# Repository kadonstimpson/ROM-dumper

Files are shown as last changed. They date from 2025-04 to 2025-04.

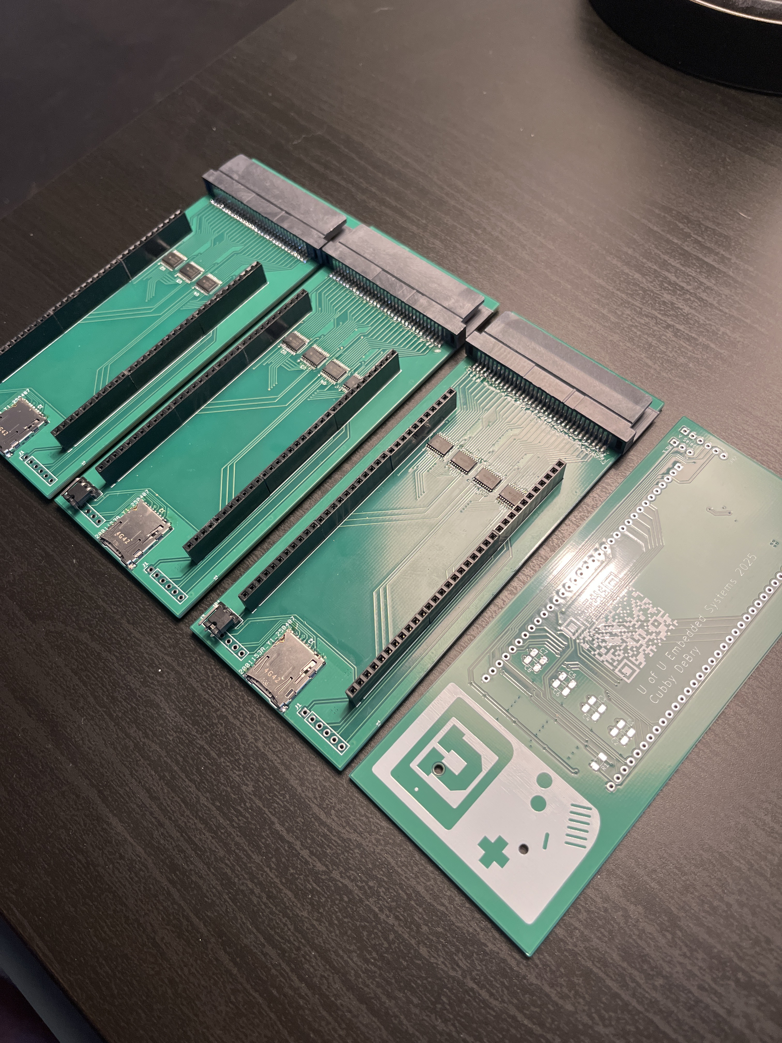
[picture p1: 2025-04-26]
Demo Material/Board_Fab.JPG

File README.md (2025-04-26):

# ROM‑Dumper for STM32F072 Discovery  
University of Utah • Embedded Systems Project

## Team Members
Cubby DeBry,  
Joshua Elieson,  
Kadon Stimpson,  
Yunzu Hou  

---

## Table of Contents
1. [About the Project](#about-the-project)  
2. [Hardware](#hardware)  
   * [Discovery‑board Modifications](#discovery-board-modifications)  
3. [Software](#software)  
   * [Supported Cartridge Types](#supported-cartridge-types)  
   * [Dumping Options](#dumping-options)  
4. [Getting Started](#getting-started)  
5. [Usage](#usage)  
6. [Roadmap / To‑Do](#roadmap--to-do)  

---

## About the Project
This project implements a **stand‑alone cartridge dumper** that interfaces classic Nintendo hand‑held game cards with an STM32F072 Discovery board.  
* **Hardware**—custom daughter‑board hosting the game‑card connector, level‑shifters and SD‑card slot.  
* **Firmware**—bank‑aware bus driver plus USB‑CDC and FatFS back‑ends.  
* **Host Tools**—minimal Python/Tk GUI for one‑click dumps on macOS, Windows, and Linux.

All design files live under `Hardware/`; Desktop tools reside in `Tools/`.

---

## Hardware
Design iteration **v1** is complete and electrically validated.  SD‑card and game‑card buses have been verified on real cartridges.

### Discovery‑board Modifications
The stock STM32F072 Discovery must be tweaked to expose additional GPIO lines:
| Component | Action |
|---|---|
| C26, C27, C28 | **Remove** |
| R38, R39, R40 | **Remove** |
| SBx (solder bridges on rear) | **Bridge** matching removed caps/resistors |

> **Orientation tip**: the Discovery board plugs into the daughter‑board with its **USB‑Mini port facing the SD‑card slot**. No directional silk is present, so double‑check before powering.

---

## Software
### Supported Cartridge Types
| System | Status | Notes |
|---|---|---|
| **Game Boy / Game Boy Color** |  | |
| &nbsp;&nbsp;No MBC | ✔ Implemented *(untested)*  | |
| &nbsp;&nbsp;MBC1 | ✔ Implemented *(untested)* | |
| &nbsp;&nbsp;MBC2 | ✔ Implemented *(untested)* | |
| &nbsp;&nbsp;MBC3 | ✔ Implemented *(untested)* | Pokemon, etc. |
| &nbsp;&nbsp;MBC5 | ✔ Implemented & **tested** | Almost all later games |
| &nbsp;&nbsp;MBC6 | ✔ Implemented *(untested)* | |
| &nbsp;&nbsp;MBC7 | ✔ Implemented *(untested)* | |
| &nbsp;&nbsp;Other/rare MBCs | ✖ Not yet | Handful of known games |
| **Game Boy Advance** | ✔ Full dumps (32 MiB assumed) | |

### Dumping Options
* **USB‑CDC** – streams data over 1 Mbaud VCP; proven with GBA cartridges.  
* **SD‑Card** – direct‐to‑FAT file dumps; already linked into MBC5 flow, pending integration for other types.

---

## Getting Started
```bash
# clone repository
git clone https://github.com/your‑org/ROM‑dumper.git
cd ROM‑dumper

# create virtual environment for host tools
python3 -m venv .venv
source .venv/bin/activate

# build firmware (requires arm‑gcc & stm32cubemx)
pio run -t upload
```

---

## Usage
### Stand‑alone (SD‑Card)
1. Insert a FAT formatted SD card.  
2. Power the board via USB. 
3. Insert cartridge
6. Press *Reset* button 
7. Retrieve `.gba`/`.gbc`/`.gb` file from SD.

### USB‑CDC
1. Power the board via USB. 
2. Run `dumperGUI.py`.
3. Select corresponding serial port from list.
4. Provide file name for dump output (including `.gba`/`.gbc`/`.gb`).
5. Press *Start Dump* button 
6. Retrieve `.gba`/`.gbc`/`.gb` file

---

## Roadmap / To‑Do
* **Mode selector**—hardware or menu to choose SD vs USB without a PC.  
* **DMA + double buffering** for both back‑ends to maximise throughput.  
* **GBA ROM trimming**—detect true ROM size to avoid 32 MiB paddings.  
* **Integrate SD flow** into all MBC drivers.
* **V2 Hardware** standalone dumper with lcd and onboard STM32.  
* **Automated self‑test** jig for production.

---

© 2025 University of Utah Embedded Systems Group • Licensed under MIT (see `LICENSE`).

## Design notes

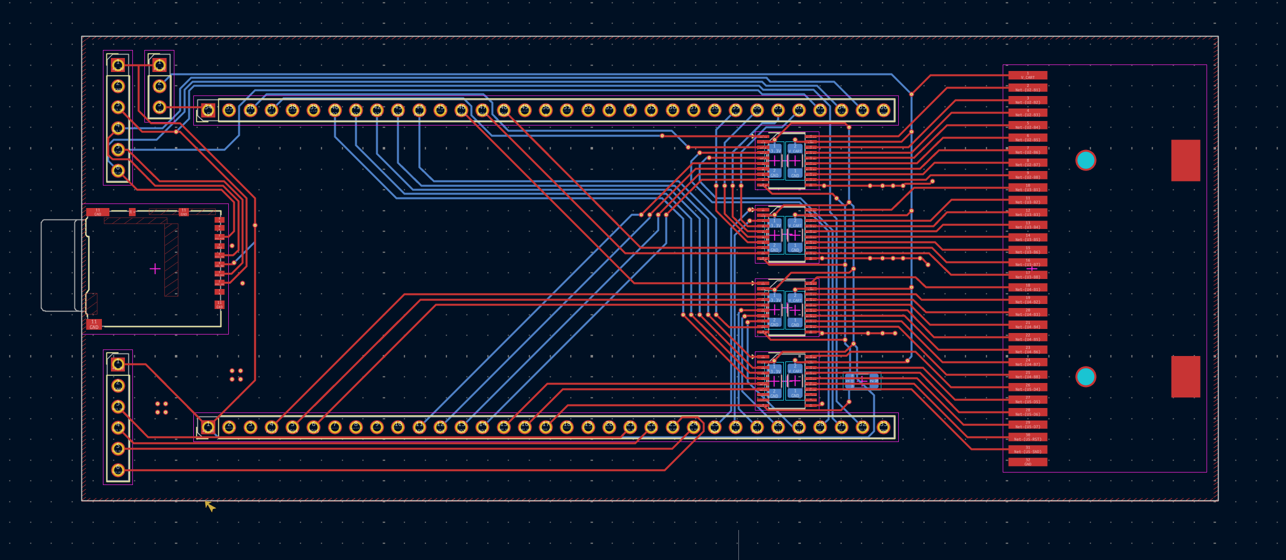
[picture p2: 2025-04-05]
Hardware/Screenshot 2025-04-05 at 1.11.22 AM.png

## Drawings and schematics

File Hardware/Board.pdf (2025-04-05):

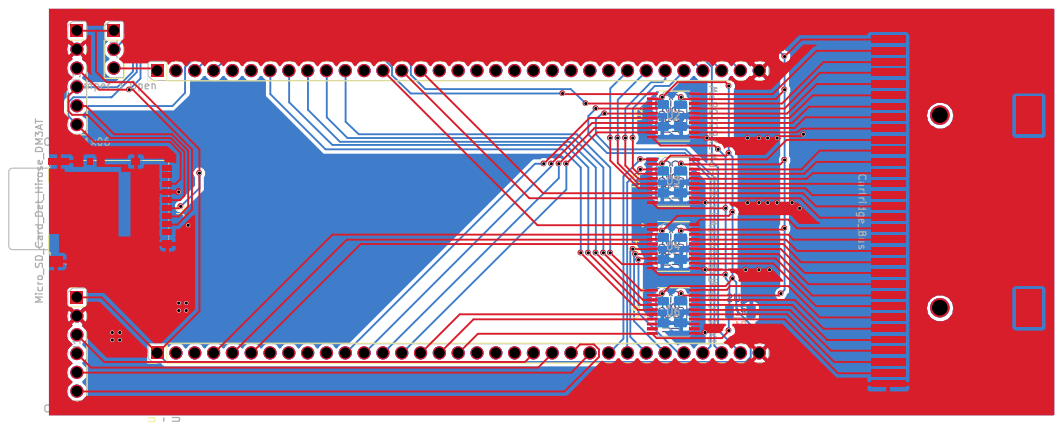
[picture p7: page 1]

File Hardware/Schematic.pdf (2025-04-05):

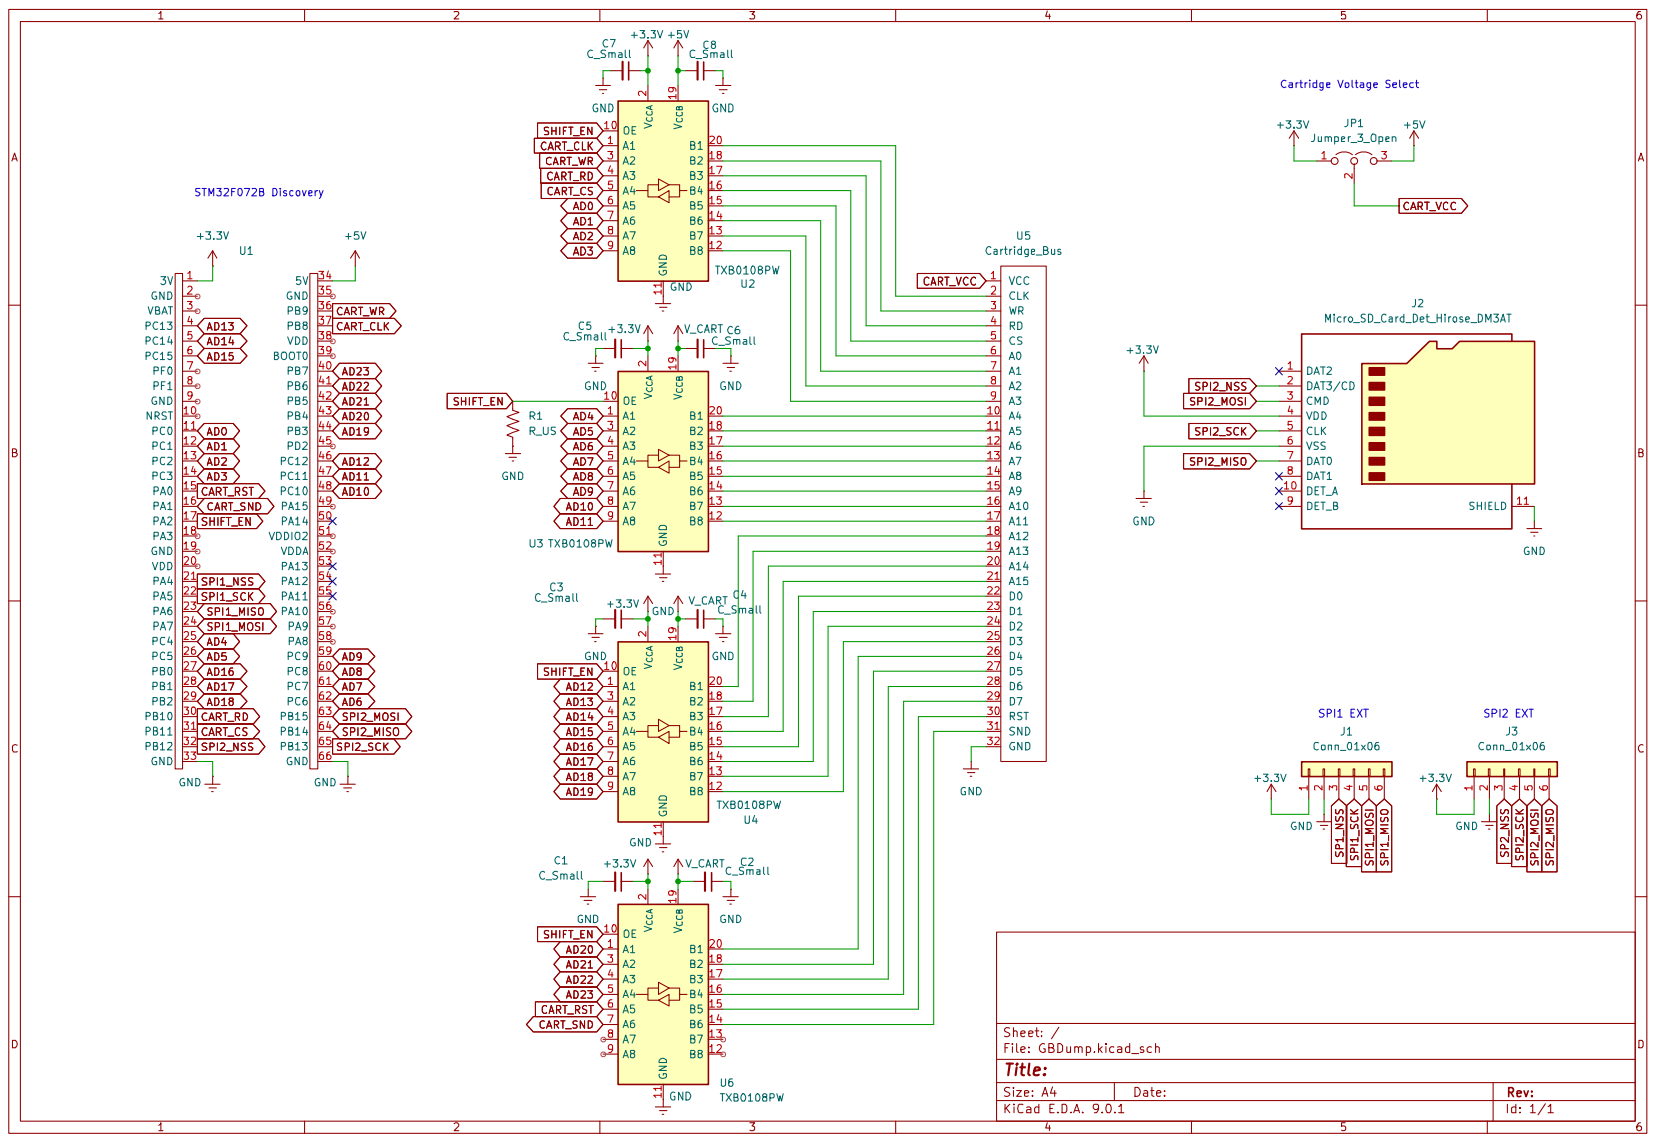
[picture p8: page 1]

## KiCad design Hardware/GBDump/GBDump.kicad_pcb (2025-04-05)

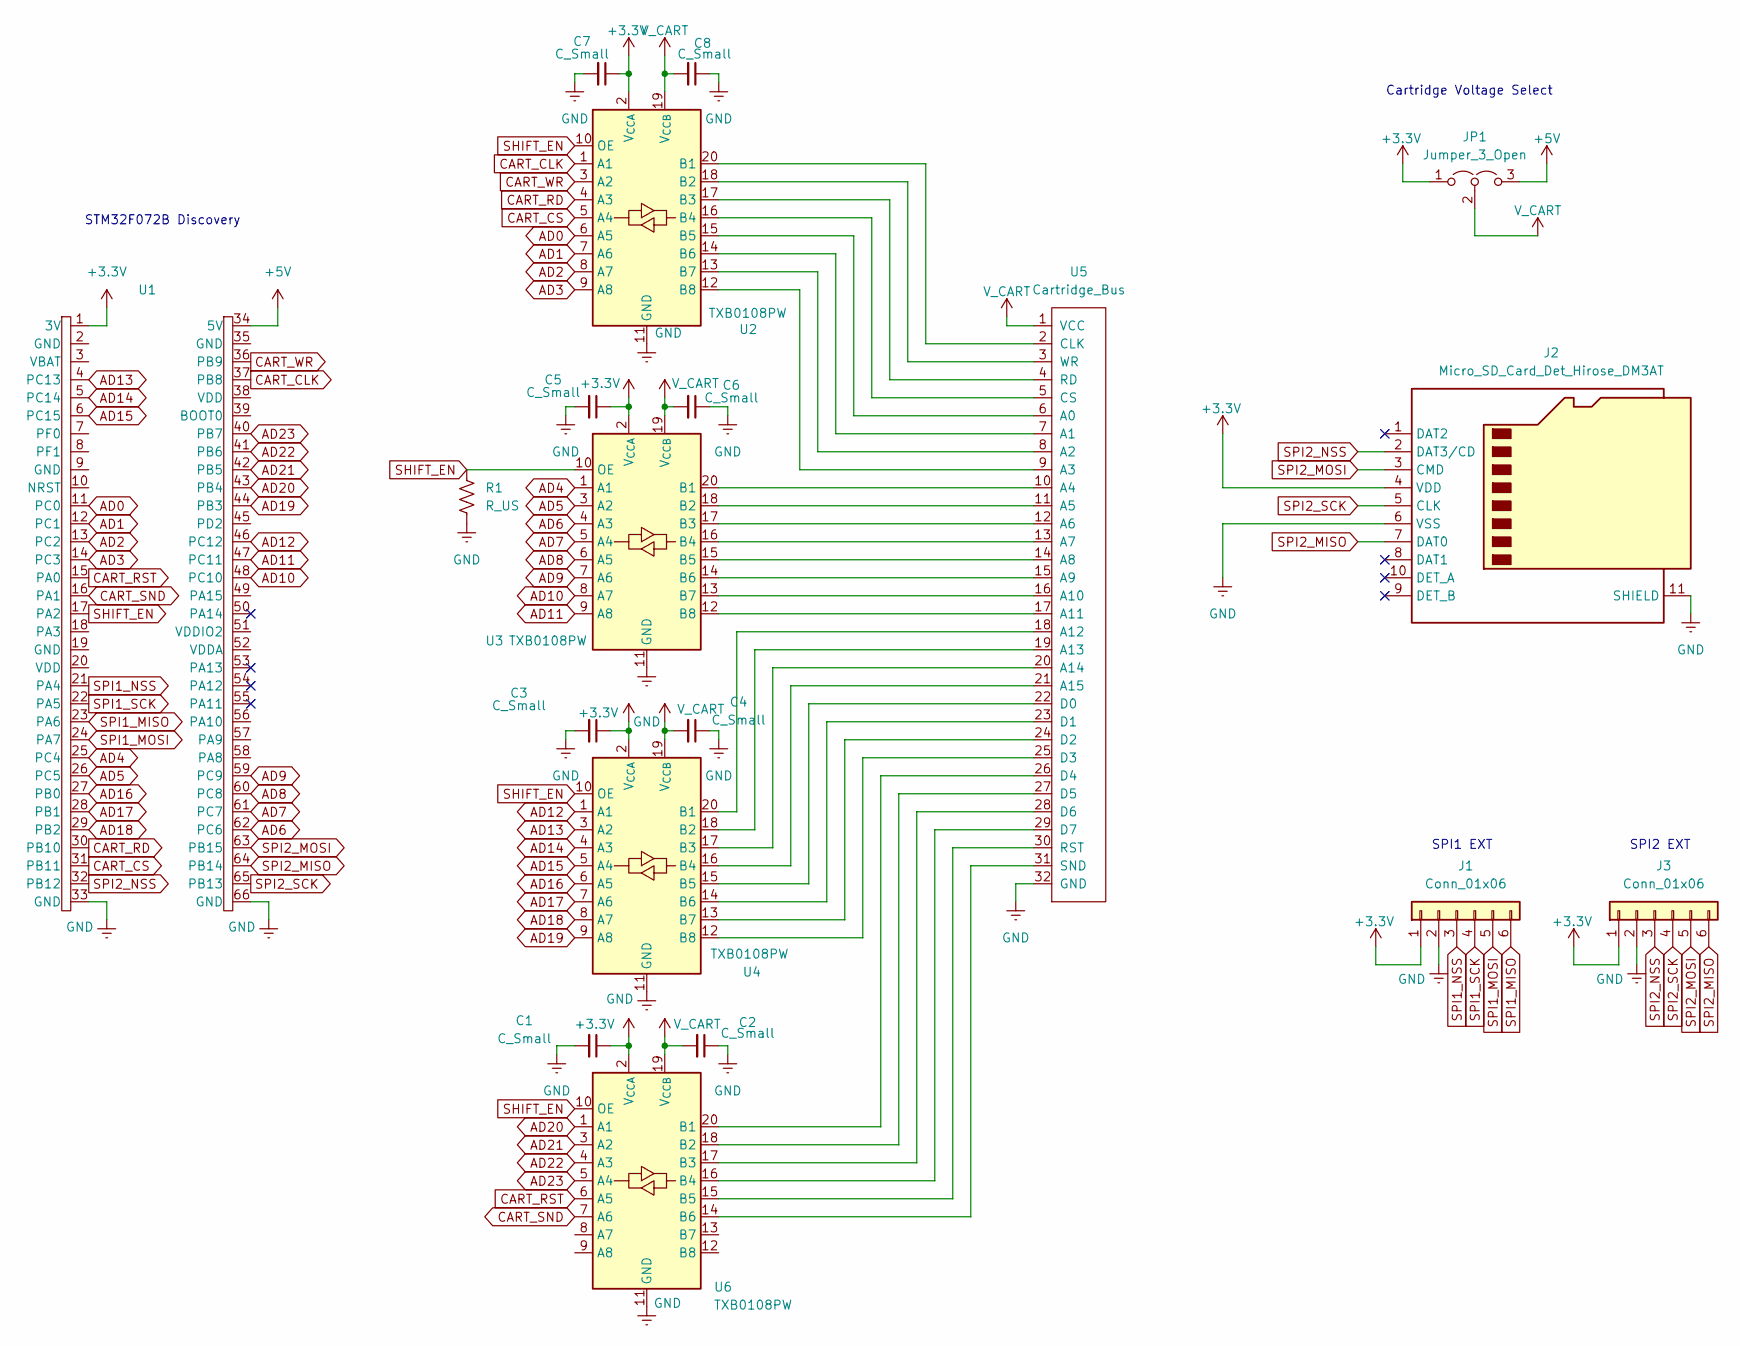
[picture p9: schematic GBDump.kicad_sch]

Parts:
C1, C2, C3, C4, C5, C6, C7, C8: C_Small; C_1206_3216Metric
J1, J3: Conn_01x06; PinHeader_1x06_P2.54mm_Vertical
J2: Micro_SD_Card_Det_Hirose_DM3AT; microSD_HC_Hirose_DM3AT-SF-PEJM5
JP1: Jumper_3_Open; PinHeader_1x03_P2.54mm_Vertical
R1: R_US; R_1206_3216Metric
U1: STM32F072B-DISCO
U2, U3, U4, U6: TXB0108PW; TSSOP-20_4.4x6.5mm_P0.65mm
U5: Cartridge_Bus; Game_Boy_Advance_Edge_Connector

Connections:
+3.3V: C1.1, C3.1, C5.1, C7.1, J1.1, J2.4 (VDD), J3.1, JP1.1 (A), U1.1 (3V), U2.2 (V_{CCA}), U3.2 (V_{CCA}), U4.2 (V_{CCA}), U6.2 (V_{CCA})
+5V: JP1.3 (B), U1.34 (5V)
AD0: U1.11 (PC0), U2.6 (A5)
AD1: U1.12 (PC1), U2.7 (A6)
AD2: U1.13 (PC2), U2.8 (A7)
AD3: U1.14 (PC3), U2.9 (A8)
AD4: U1.25 (PC4), U3.1 (A1)
AD5: U1.26 (PC5), U3.3 (A2)
AD6: U1.62 (PC6), U3.4 (A3)
AD7: U1.61 (PC7), U3.5 (A4)
AD8: U1.60 (PC8), U3.6 (A5)
AD9: U1.59 (PC9), U3.7 (A6)
AD10: U1.48 (PC10), U3.8 (A7)
AD11: U1.47 (PC11), U3.9 (A8)
AD12: U1.46 (PC12), U4.1 (A1)
AD13: U1.4 (PC13), U4.3 (A2)
AD14: U1.5 (PC14), U4.4 (A3)
AD15: U1.6 (PC15), U4.5 (A4)
AD16: U1.27 (PB0), U4.6 (A5)
AD17: U1.28 (PB1), U4.7 (A6)
AD18: U1.29 (PB2), U4.8 (A7)
AD19: U1.44 (PB3), U4.9 (A8)
AD20: U1.43 (PB4), U6.1 (A1)
AD21: U1.42 (PB5), U6.3 (A2)
AD22: U1.41 (PB6), U6.4 (A3)
AD23: U1.40 (PB7), U6.5 (A4)
CART_CLK: U1.37 (PB8), U2.1 (A1)
CART_CS: U1.31 (PB11), U2.5 (A4)
CART_RD: U1.30 (PB10), U2.4 (A3)
CART_RST: U1.15 (PA0), U6.6 (A5)
CART_SND: U1.16 (PA1), U6.7 (A6)
CART_WR: U1.36 (PB9), U2.3 (A2)
GND: C1.2, C2.1, C3.2, C4.1, C5.2, C6.1, C7.2, C8.1, J1.2, J2.6 (VSS), J2.11 (SHIELD), J3.2, R1.2, U1.33 (GND), U1.66 (GND), U2.11 (GND), U3.11 (GND), U4.11 (GND), U5.32 (GND), U6.11 (GND)
unnamed: U2.20 (B1), U5.2 (CLK~)
unnamed: U2.18 (B2), U5.3 (WR)
unnamed: U2.17 (B3), U5.4 (RD)
unnamed: U2.16 (B4), U5.5 (CS)
unnamed: U2.15 (B5), U5.6 (A0)
unnamed: U2.14 (B6), U5.7 (A1)
unnamed: U2.13 (B7), U5.8 (A2)
unnamed: U2.12 (B8), U5.9 (A3)
unnamed: U3.20 (B1), U5.10 (A4)
unnamed: U3.18 (B2), U5.11 (A5)
unnamed: U3.17 (B3), U5.12 (A6)
unnamed: U3.16 (B4), U5.13 (A7)
unnamed: U3.15 (B5), U5.14 (A8)
unnamed: U3.14 (B6), U5.15 (A9)
unnamed: U3.13 (B7), U5.16 (A10)
unnamed: U3.12 (B8), U5.17 (A11)
unnamed: U4.20 (B1), U5.18 (A12)
unnamed: U4.18 (B2), U5.19 (A13)
unnamed: U4.17 (B3), U5.20 (A14)
unnamed: U4.16 (B4), U5.21 (A15)
unnamed: U4.15 (B5), U5.22 (D0)
unnamed: U4.14 (B6), U5.23 (D1)
unnamed: U4.13 (B7), U5.24 (D2)
unnamed: U4.12 (B8), U5.25 (D3)
unnamed: U5.26 (D4), U6.20 (B1)
unnamed: U5.27 (D5), U6.18 (B2)
unnamed: U5.28 (D6), U6.17 (B3)
unnamed: U5.29 (D7), U6.16 (B4)
unnamed: U5.30 (RST), U6.15 (B5)
unnamed: U5.31 (SND), U6.14 (B6)
SHIFT_EN: R1.1, U1.17 (PA2), U2.10 (OE), U3.10 (OE), U4.10 (OE), U6.10 (OE)
SPI1_MISO: J1.6, U1.23 (PA6)
SPI1_MOSI: J1.5, U1.24 (PA7)
SPI1_NSS: J1.3, U1.21 (PA4)
SPI1_SCK: J1.4, U1.22 (PA5)
SPI2_MISO: J2.7 (DAT0), J3.6, U1.64 (PB14)
SPI2_MOSI: J2.3 (CMD), J3.5, U1.63 (PB15)
SPI2_NSS: J2.2 (DAT3/CD), J3.3, U1.32 (PB12)
SPI2_SCK: J2.5 (CLK), J3.4, U1.65 (PB13)
V_CART: C2.2, C4.2, C6.2, C8.2, JP1.2 (C), U2.19 (V_{CCB}), U3.19 (V_{CCB}), U4.19 (V_{CCB}), U5.1 (VCC), U6.19 (V_{CCB})

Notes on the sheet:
Cartridge Voltage Select
STM32F072B Discovery
SPI1 EXT
SPI2 EXT

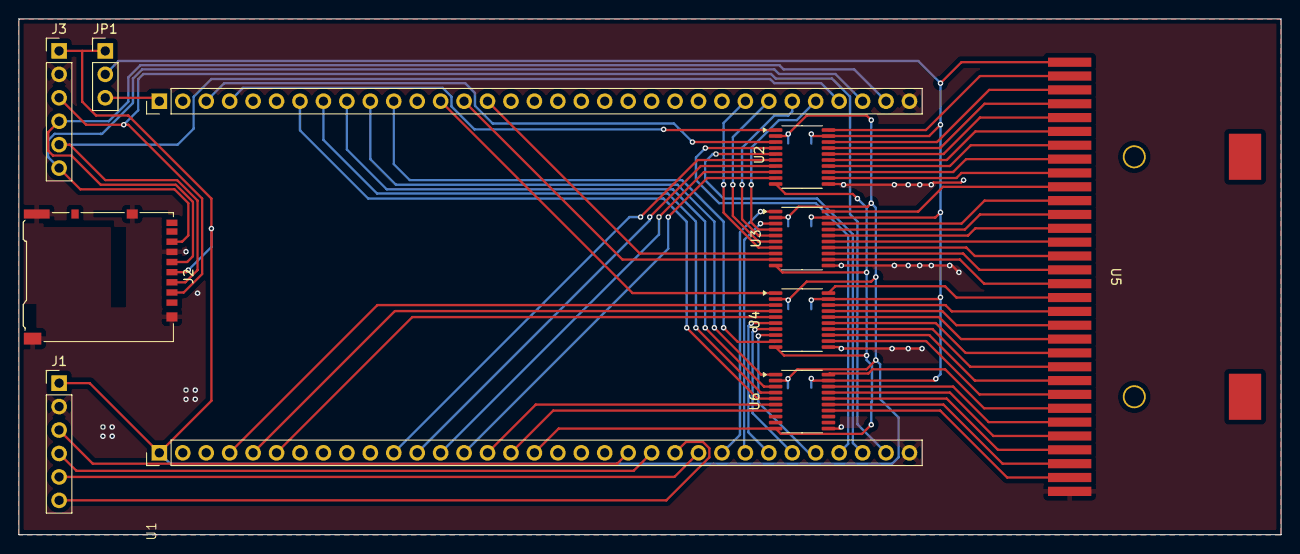
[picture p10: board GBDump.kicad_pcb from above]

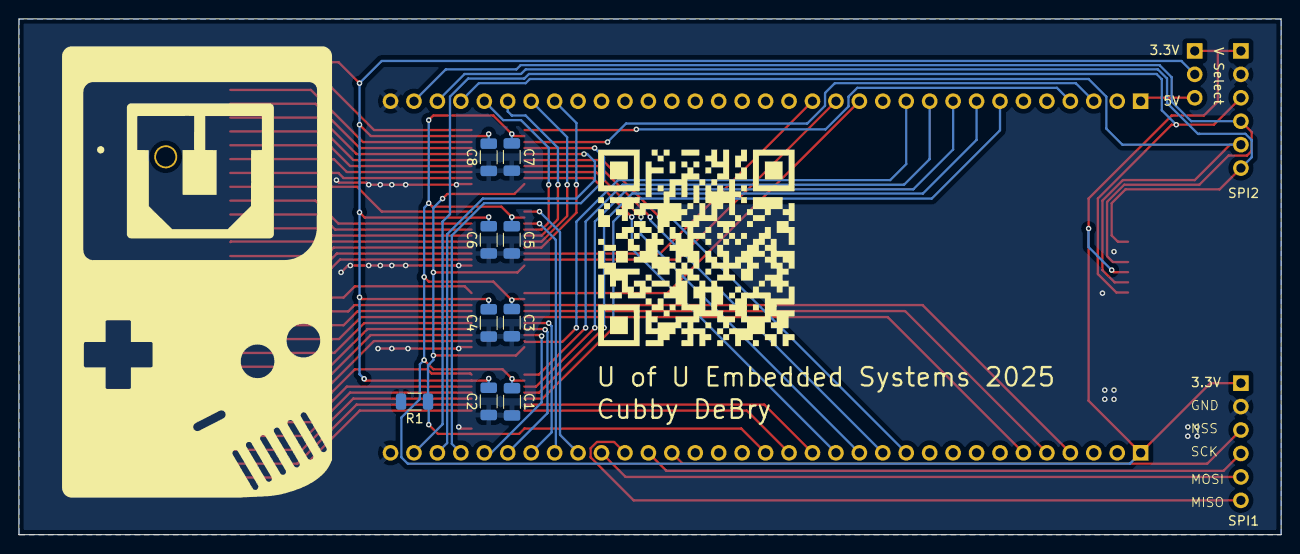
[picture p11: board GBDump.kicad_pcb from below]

Board: 2 copper layers, 136.8 x 55.9 mm, 19 parts (9 on the bottom side), 73 nets.

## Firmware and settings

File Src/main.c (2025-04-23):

#include "stm32f0xx_hal.h"
#include <string.h>
#include <stdio.h>
#include "GBC.h"
#include "GBA.h"
#include "sd.h"
#include "main.h"
#include "uart.h"
#include "usb_device.h"
#include "usbd_cdc_if.h"

volatile uint32_t last_isr;

void Init_All(void);
static void Gyro_SPI2_Init();
static void USB_ClockEnable();

int main(void) {
  Init_All();   // Add any additional initialization here

  GBA_test();   // Test GBA stuff here

  // GBC_test();

  sd_test();

  while(1){}
}

void Init_All(){
  HAL_Init();
  SystemClock_Config();
  USB_ClockEnable();

  __HAL_RCC_GPIOA_CLK_ENABLE();  // Enable GPIOA clock
  __HAL_RCC_GPIOB_CLK_ENABLE();
  __HAL_RCC_GPIOC_CLK_ENABLE();

  __HAL_RCC_PWR_CLK_ENABLE();   // Enable USB clock and power
  MX_USB_DEVICE_Init();      // Hangs, removed temporarily
 
  HAL_PWR_EnableBkUpAccess(); // Enable access to backup domain

  RCC->BDCR &= ~RCC_BDCR_LSEON; // Disable LSE oscillator to free PC14 and PC15

  while (RCC->BDCR & RCC_BDCR_LSERDY) {}  // Wait until LSE is fully disabled

  Gyro_SPI2_Init();
  GPIO_UART1_Init();  
  UART1_Init(); 
  setvbuf(stdout, NULL, _IONBF, 0); // make printf unbuffered 

  GPIO_InitTypeDef RDWR = {0};  // Upper address bus
  RDWR.Pin = GPIO_PIN_9 | GPIO_PIN_10 | GPIO_PIN_11;
  RDWR.Mode = GPIO_MODE_OUTPUT_PP;  // Push-pull output
  RDWR.Pull = GPIO_NOPULL;
  RDWR.Speed = GPIO_SPEED_FREQ_LOW;

  GPIO_InitTypeDef RST = {0};  // Cart Reset
  RST.Pin = GPIO_PIN_0;
  RST.Mode = GPIO_MODE_OUTPUT_PP;  // Push-pull output
  RST.Pull = GPIO_NOPULL;
  RST.Speed = GPIO_SPEED_FREQ_LOW;
  
  HAL_GPIO_Init(GPIOB, &RDWR);
  HAL_GPIO_Init(GPIOA, &RST);

  shift_enable();

  HAL_GPIO_WritePin(GPIOB, GPIO_PIN_10, GPIO_PIN_SET);      // Read disable
  HAL_GPIO_WritePin(GPIOB, GPIO_PIN_9, GPIO_PIN_SET);       // Write disable
  // HAL_GPIO_WritePin(GPIOB, GPIO_PIN_11, GPIO_PIN_RESET);    // Pull /CS low

  HAL_GPIO_WritePin(GPIOA, GPIO_PIN_0, GPIO_PIN_RESET);     // Reset cart
  HAL_Delay(10);
  HAL_GPIO_WritePin(GPIOA, GPIO_PIN_0, GPIO_PIN_SET);
  HAL_Delay(10);
}

static void Gyro_SPI2_Init(void)  // set gyro pins to high impedence
{
    __HAL_RCC_GPIOB_CLK_ENABLE();
    __HAL_RCC_SPI2_CLK_ENABLE();

    GPIO_InitTypeDef g = {0};

    g.Pin       = GPIO_PIN_13 | GPIO_PIN_14 | GPIO_PIN_15;  // PB13 - SCK, PB14 - MISO, PB15 - MOSI
    g.Mode      = GPIO_MODE_AF_PP;
    g.Pull      = GPIO_NOPULL;
    g.Speed     = GPIO_SPEED_FREQ_HIGH;
    g.Alternate = GPIO_AF0_SPI2;
    HAL_GPIO_Init(GPIOB, &g);

    __HAL_RCC_GPIOC_CLK_ENABLE(); // PC0 - CS
    g.Pin   = GPIO_PIN_0;
    g.Mode  = GPIO_MODE_OUTPUT_PP;
    g.Speed = GPIO_SPEED_FREQ_HIGH;
    HAL_GPIO_Init(GPIOC, &g);
    HAL_GPIO_WritePin(GPIOC, GPIO_PIN_0, GPIO_PIN_SET);  // CS high

    static SPI_HandleTypeDef h;
    h.Instance               = SPI2;
    h.Init.Mode              = SPI_MODE_MASTER;
    h.Init.Direction         = SPI_DIRECTION_2LINES;
    h.Init.DataSize          = SPI_DATASIZE_8BIT;
    h.Init.CLKPolarity       = SPI_POLARITY_LOW;
    h.Init.CLKPhase          = SPI_PHASE_1EDGE;
    h.Init.NSS               = SPI_NSS_SOFT;
    h.Init.BaudRatePrescaler = SPI_BAUDRATEPRESCALER_256;
    h.Init.FirstBit          = SPI_FIRSTBIT_MSB;
    HAL_SPI_Init(&h);

    uint8_t wr[2];

    /* 1. Power‑down the device (CTRL_REG1, addr 0x20) */
    wr[0] = 0x20;               // address, MSB=0 → write
    wr[1] = 0x00;               // PD=0, ODR=00 => power‑down
    HAL_GPIO_WritePin(GPIOC, GPIO_PIN_0, GPIO_PIN_RESET);
    HAL_SPI_Transmit(&h, wr, 2, HAL_MAX_DELAY);
    HAL_GPIO_WritePin(GPIOC, GPIO_PIN_0, GPIO_PIN_SET);

    /* 2. Disable every interrupt on both pins (CTRL_REG3, addr 0x22) */
    wr[0] = 0x22;
    wr[1] = 0x10;               // all I2_/I1_ high impedence
    HAL_GPIO_WritePin(GPIOC, GPIO_PIN_0, GPIO_PIN_RESET);
    HAL_SPI_Transmit(&h, wr, 2, HAL_MAX_DELAY);
    HAL_GPIO_WritePin(GPIOC, GPIO_PIN_0, GPIO_PIN_SET);
}

static void USB_ClockEnable(void){
  __HAL_RCC_HSI48_ENABLE();
  while(!__HAL_RCC_GET_FLAG(RCC_FLAG_HSI48RDY));

  __HAL_RCC_USB_CONFIG(RCC_USBCLKSOURCE_HSI48);
  __HAL_RCC_CRS_CLK_ENABLE();
  __HAL_RCC_USB_CLK_ENABLE();
}

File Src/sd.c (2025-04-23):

#include "sd.h"
#include "diskio.h"
#include "ff.h"
#include "rtc.h"

static DSTATUS sd_stat = STA_NOINIT;
extern RTC_HandleTypeDef hrtc;

void sd_cs_low(void)
{
  HAL_GPIO_WritePin(GPIOB, GPIO_PIN_12, GPIO_PIN_RESET);
}

void sd_cs_high(void)
{
  HAL_GPIO_WritePin(GPIOB, GPIO_PIN_12, GPIO_PIN_SET);
}

// void sd_test()
// {
//   //init rtc
//   MX_RTC_Init();
//   rtc_check_and_set();

//   FATFS fs;
//   FIL file;
//   UINT bw;

//   if (f_mount(&fs, "", 1) == FR_OK) //mount filesystem (inits sd card)
//   {
//     HAL_GPIO_WritePin(GPIOC, GPIO_PIN_6, GPIO_PIN_SET);  // Turn on red LED
//     if (f_open(&file, "helloworld.txt", FA_WRITE | FA_CREATE_ALWAYS) == FR_OK)
//     {
//       f_write(&file, "Hello, STM32 SD write!\n", 23, &bw);
//       f_close(&file);
//       HAL_GPIO_WritePin(GPIOC, GPIO_PIN_7, GPIO_PIN_SET);  // Turn on LED
//     }

//     char buffer[64];
//     UINT br;
//     if (f_open(&file, "helloworld.txt", FA_READ) == FR_OK)
//     {
//       f_read(&file, buffer, sizeof(buffer) - 1, &br);
//       buffer[br] = 0;
//       f_close(&file);
//       // Output buffer to UART or screen
//     }
//   }
// }
void sd_test()
{
  FATFS fs;
  FIL file;
  UINT bw, br;
  char buffer[64];
  char msg[64];

  // Init LEDs on PC6–PC9
  RCC->AHBENR |= RCC_AHBENR_GPIOCEN;
  GPIO_InitTypeDef gpioInit = {
    .Pin = GPIO_PIN_6 | GPIO_PIN_7 | GPIO_PIN_8 | GPIO_PIN_9,
    .Mode = GPIO_MODE_OUTPUT_PP,
    .Pull = GPIO_NOPULL,
    .Speed = GPIO_SPEED_FREQ_LOW
  };
  HAL_GPIO_Init(GPIOC, &gpioInit);
  HAL_GPIO_WritePin(GPIOC, GPIO_PIN_6 | GPIO_PIN_7 | GPIO_PIN_8 | GPIO_PIN_9, GPIO_PIN_RESET);

  // Initialize RTC
  MX_RTC_Init();
  rtc_check_and_set();

  // Try to mount
  FRESULT res = f_mount(&fs, "", 1);
  printf("f_mount result = %d\r\n", res);
  if (res != FR_OK) return;
  HAL_GPIO_WritePin(GPIOC, GPIO_PIN_6, GPIO_PIN_SET); // Mount OK

  // Try to open file for writing
  res = f_open(&file, "helloworld.txt", FA_WRITE | FA_CREATE_ALWAYS);
  printf("f_open result = %d\r\n", res);
  if (res != FR_OK) return;

  // Write to file
  res = f_write(&file, "Hello, STM32 SD write!\n", 23, &bw);
  sprintf(msg, "f_write result = %d, bytes = %u\r\n", res, bw);
  send_serial(msg);
  f_close(&file);
  HAL_GPIO_WritePin(GPIOC, GPIO_PIN_7, GPIO_PIN_SET); // Write OK

  // Try to read it back
  res = f_open(&file, "helloworld.txt", FA_READ);
  printf("f_open (read) = %d\r\n", res);
  if (res != FR_OK) return;

  res = f_read(&file, buffer, sizeof(buffer) - 1, &br);
  buffer[br] = 0;
  printf("f_read = %d, read %u bytes: %s\r\n", res, br, buffer);
  f_close(&file);
  HAL_GPIO_WritePin(GPIOC, GPIO_PIN_8, GPIO_PIN_SET); // Read OK

  // All done
  HAL_GPIO_WritePin(GPIOC, GPIO_PIN_9, GPIO_PIN_SET); // Finish LED
}


void init_spi_sd()
{
  // Enable GPIOB, SPI2
  RCC->AHBENR |= RCC_AHBENR_GPIOBEN;
  RCC->APB1ENR |= RCC_APB1ENR_SPI2EN;

  // PB13-SCK, PB14-MISO, PB15-MOSI: AF0
  GPIO_InitTypeDef initSPI2 = {
    .Pin = GPIO_PIN_13 | GPIO_PIN_14 | GPIO_PIN_15,
    .Mode = GPIO_MODE_AF_PP,
    .Pull = GPIO_NOPULL,
    .Speed = GPIO_SPEED_FREQ_LOW,
    .Alternate = GPIO_AF0_SPI2
  };
  HAL_GPIO_Init(GPIOB, &initSPI2);

  // PB12-CS: Output
  GPIO_InitTypeDef initCS = {
    .Pin = GPIO_PIN_12,
    .Mode = GPIO_MODE_OUTPUT_PP,
    .Pull = GPIO_NOPULL,
    .Speed = GPIO_SPEED_FREQ_LOW
  };
  HAL_GPIO_Init(GPIOB, &initCS);
  sd_cs_high(); // Default CS high

  // SPI2 configuration
  SPI2->CR1 &= ~SPI_CR1_SPE; // disable SPI
  SPI2->CR1 &= ~SPI_CR1_BR;
  SPI2->CR1 |=  SPI_CR1_BR_0 | SPI_CR1_BR_1 | SPI_CR1_BR_2; // slowest

  SPI2->CR1 |= SPI_CR1_MSTR | SPI_CR1_SSM | SPI_CR1_SSI; // master, SW NSS
  SPI2->CR2 &= ~SPI_CR2_DS;
  SPI2->CR2 |= SPI_CR2_DS_0 | SPI_CR2_DS_1 | SPI_CR2_DS_2 | SPI_CR2_FRXTH; // 8-bit

  SPI2->CR1 |= SPI_CR1_SPE; // enable SPI
}

void set_spi_speed_fast(void) 
{
  SPI2->CR1 &= ~SPI_CR1_SPE;
  SPI2->CR1 &= ~SPI_CR1_BR;
  SPI2->CR1 |= SPI_CR1_BR_1; // /8
  SPI2->CR1 |= SPI_CR1_SPE;
}


uint8_t sd_spi_send(uint8_t data)
{
  while (!(SPI2->SR & SPI_SR_TXE));
  *((__IO uint8_t*)&SPI2->DR) = data;
  while (!(SPI2->SR & SPI_SR_RXNE));
  return *((__IO uint8_t*)&SPI2->DR);
}

uint8_t sd_spi_recv()
{
  return sd_spi_send(0xFF);
}

// void sd_send_cmd0()
// {
//   for (int i = 0; i < 10; i++) sd_spi_send(0xFF); // 80 clocks

//   sd_cs_low();

//   sd_spi_send(0x40);     // CMD0
//   sd_spi_send(0x00);
//   sd_spi_send(0x00);
//   sd_spi_send(0x00);
//   sd_spi_send(0x00);
//   sd_spi_send(0x95);     // Valid CRC for CMD0

//   for (int i = 0; i < 8; i++) {
//     uint8_t r = sd_spi_recv();
//     if (r == 0x01) break;
//   }

//   sd_cs_high();
//   sd_spi_recv(); // extra 8 clocks
// }

uint8_t sd_send_cmd(uint8_t cmd, uint32_t arg, uint8_t crc) 
{
  sd_cs_high();
  sd_spi_recv(); // idle
  sd_cs_low();
  sd_spi_recv(); // extra 8 clocks

  sd_spi_send(0x40 | cmd);
  sd_spi_send((arg >> 24) & 0xFF);
  sd_spi_send((arg >> 16) & 0xFF);
  sd_spi_send((arg >> 8) & 0xFF);
  sd_spi_send(arg & 0xFF);
  sd_spi_send(crc);

  // Wait for a valid response
  for (int i = 0; i < 10; i++) {
    uint8_t r = sd_spi_recv();
    if ((r & 0x80) == 0) return r;
  }

  return 0xFF; // timeout
}


DSTATUS init_sd()
{
  init_spi_sd();
  sd_cs_high();
  for (int i = 0; i < 10; i++) sd_spi_recv();

  // CMD0: Go to idle
  uint8_t r = sd_send_cmd(0, 0x00000000, 0x95);
  if (r != 0x01) return sd_stat = STA_NOINIT;

  // CMD8: Check voltage range
  r = sd_send_cmd(8, 0x000001AA, 0x87);
  if (r != 0x01) return sd_stat = STA_NOINIT;

  uint8_t r7[4];
  for (int i = 0; i < 4; i++) r7[i] = sd_spi_recv();
  if (r7[2] != 0x01 || r7[3] != 0xAA) return sd_stat = STA_NOINIT;

  // ACMD41 loop
  for (int i = 0; i < 1000; i++) {
    sd_send_cmd(55, 0, 0x65); // CMD55
    r = sd_send_cmd(41, 0x40000000, 0x77); // ACMD41 with HCS
    if (r == 0x00) break;
    HAL_Delay(1);
  }
  set_spi_speed_fast(); //init done, speed up bus
  if (r != 0x00) return sd_stat = STA_NOINIT;

  // CMD58: Read OCR
  r = sd_send_cmd(58, 0, 0xFD);
  if (r != 0x00) return sd_stat = STA_NOINIT;

  for (int i = 0; i < 4; i++) sd_spi_recv(); // discard OCR

  sd_cs_high();
  sd_spi_recv();


  sd_stat = 0; // Ready
  return sd_stat;
}

DRESULT sd_read(BYTE *buff, LBA_t sector, UINT count)
{
  if (sd_stat & STA_NOINIT) return RES_NOTRDY;
  if (count != 1) return RES_PARERR; // Only single block supported

  if (sd_send_cmd(17, sector, 0x01) != 0x00) {
    sd_cs_high();
    return RES_ERROR;
  }

  // Wait for data token 0xFE
  for (int i = 0; i < 100000; i++) {
    uint8_t token = sd_spi_recv();
    if (token == 0xFE) break;
    if (i == 99999) {
      sd_cs_high();
      return RES_ERROR;
    }
  }

  // Read 512 bytes
  for (int i = 0; i < 512; i++) {
    buff[i] = sd_spi_recv();
  }

  // Discard CRC
  sd_spi_recv();
  sd_spi_recv();

  sd_cs_high();
  sd_spi_recv(); // extra clock
  return RES_OK;
}
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

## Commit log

2025-03-31 Started schematic, made STMDiscovery symbol, added TXB0108 level shifters.
    [GBDump.kicad_pcb, GBDump.kicad_sch]
2025-03-31 Finished address and data bus, level shifting power and ground, jumper for voltage selection.
    [GBDump.kicad_sch]
2025-03-31 Added SPI header, symbol files
    [GBDump.kicad_sch]
2025-04-04 Added PDF version of schematic
2025-04-05 Added SD interface and level shift enable pin with pull down
    [GBDump.kicad_sch]
2025-04-05 Fixed CART_VCC label
    [GBDump.kicad_sch]
2025-04-05 Finished board layout and routing, will add silkscreen.
    [GBDump.kicad_pcb, GBDump.kicad_sch]
2025-04-05 PCB finished other than silkscreen.
2025-04-05 Finished silkscreen, generated gerbers.
    [GBDump-B_Cu.gbr, GBDump-B_Mask.gbr, GBDump-B_Paste.gbr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]
2025-04-10 Finished UART2 initialization. Added UART test message.
2025-04-11 Removed UART2 functions.
2025-04-15 Added functions I've been testing on a different board in gameboy.c, move uart and initialization to uart.c
2025-04-15 Moved UART functions.
2025-04-16 added discovery board datasheets
2025-04-19 A few minor bug fixes, fixed /RST pin.
    [GBC.c, main.c]
2025-04-19 Fixed bank switching and printf, working on MBC5 handler.
    [GBC.c, main.c, system_setup.c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]
2025-04-19 Added preliminary GBA functions. Worked out issue overwriting all of GPIOB making RD and CS to drop causing high impedence state. Reading semi-legible data, cart name appears scrambled.
    [GBA.c, GBC.c, main.c]
2025-04-20 Tweaked test dump, added byte swap, initial cs toggle to clear cart. First working GBA dump.
    [GBA.c]
2025-04-20 Tried blocking to increase speeds, UART is topping out maybe USB CDC faster. Need to add functions to query rom header and handle dump.
2025-04-21 Added MBC1 dump function. Still looking for games to test with. Bank switch function was intended for MBC5 and SHOULD still work for other switching. If having problems check that first.
    [GBC.c]
2025-04-21 Fixed naming issue. Implemented MBC2 and MBC1.
    [GBC.c]
2025-04-21 Fixed naming issue. Fixed wrong call in switch for MBC1.
    [GBC.c]
2025-04-21 Okay bank switching methods are waaaay more diverse. Implemented much more comprehensive bank switcher (maybe 98% of games?). Again, need to find carts to test.
2025-04-22 Fixed USB cdc initialization errors.
    [main.c]
2025-04-22 Simple python gui, includes dropdown, text entry, button
2025-04-25 Added simple handshake to GUI, fixed missed bytes in GBA.
    [GBA.c, dumperGUI.py]
